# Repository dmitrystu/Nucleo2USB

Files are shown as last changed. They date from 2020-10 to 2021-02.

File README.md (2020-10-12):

## NUCLEO2USB SHIELD

NUCLEO2USB SHUELD

+ Compatible with NUCLEO-64 boards
+ Can be configured as 2xOTGFS, 1xOTGFS, 2xDEVFS, 1xDEVFS, 1xDEVFS+1xOTGFS
+ Can provide power to the baseboard from USB1 USB2 and STLINK(U5V) via E5V pin
+ USB FS/LS override jumper (for the NUCLEO-F303RE / NUCLEO-F103RB)
+ 2x micro USB TYPE B connectors
+ ESCDA5V3SC6 USB ESD protection
+ LM3526L USB-OTG power switch with over-current protection

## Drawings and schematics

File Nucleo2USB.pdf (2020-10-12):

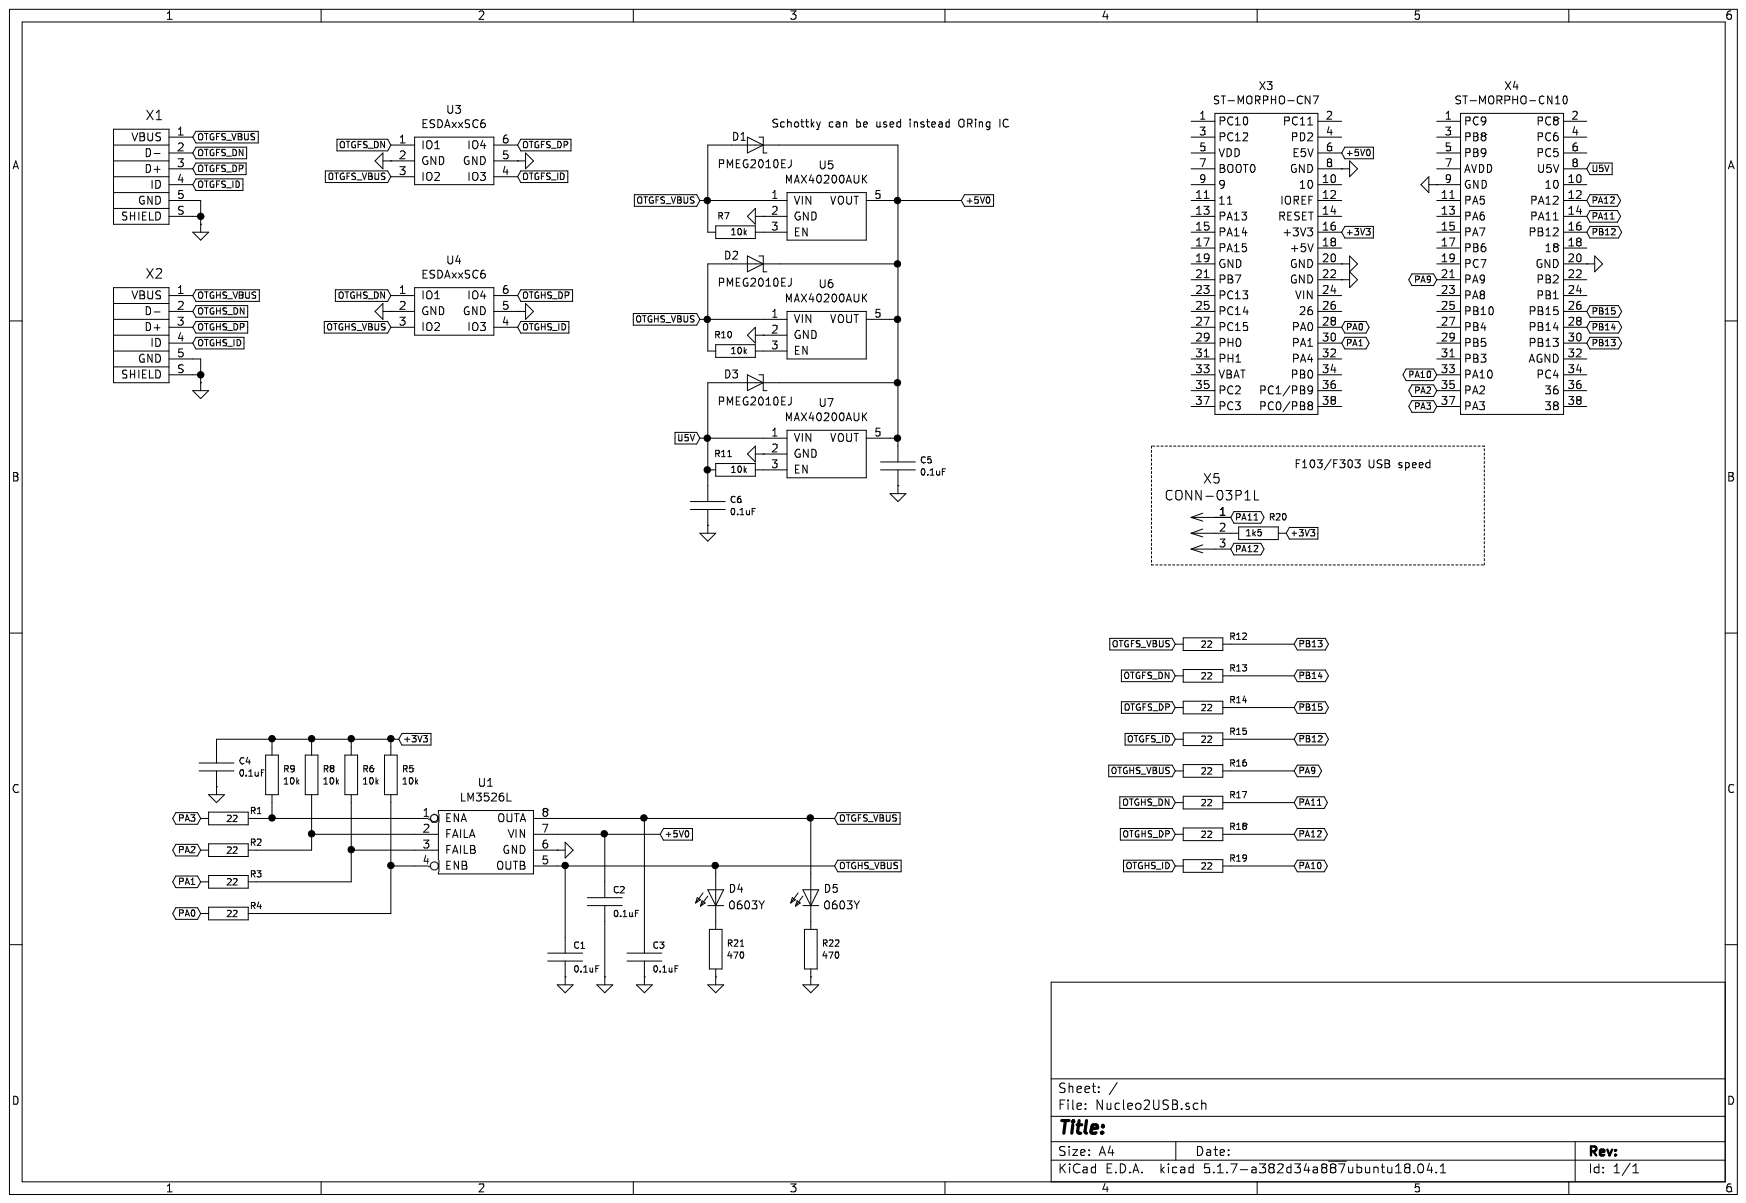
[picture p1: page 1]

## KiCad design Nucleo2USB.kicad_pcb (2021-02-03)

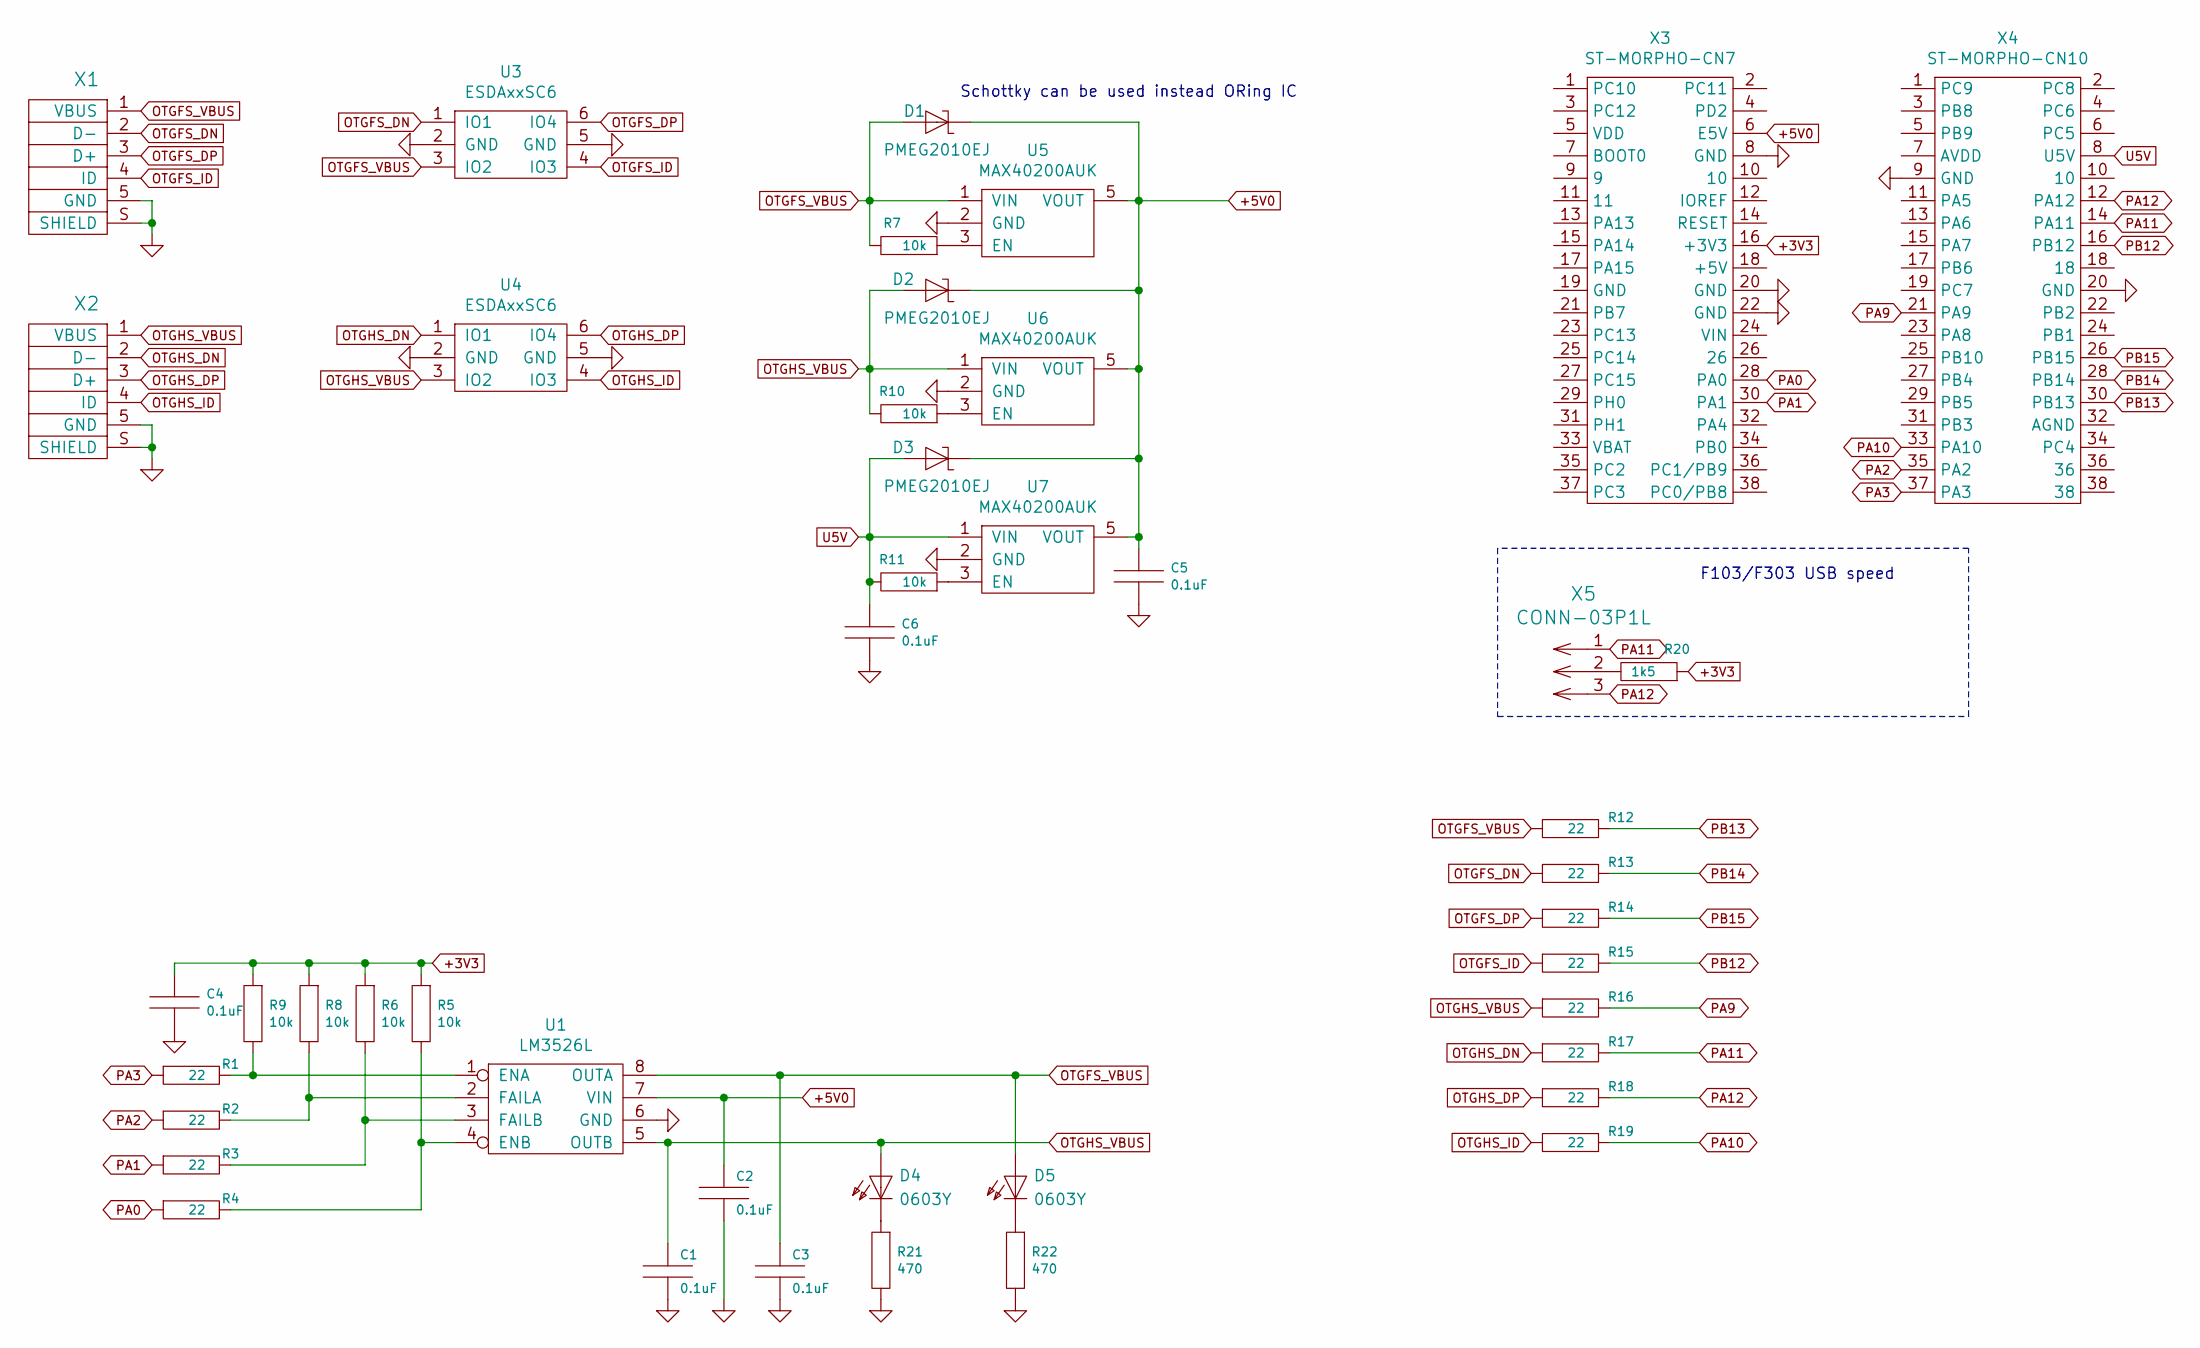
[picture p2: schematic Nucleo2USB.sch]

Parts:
C1, C2, C3, C4, C5, C6: 0.1uF; SMD-0603C
D1, D2, D3: PMEG2010EJ; SOD-123F
D4, D5: 0603Y; LED-0603
R1, R2, R3, R4, R12, R13, R14, R15, R16, R17, R18, R19: 22; SMD-0603R
R5, R6, R7, R8, R9, R10, R11: 10k; SMD-0603R
R20: 1k5; SMD-0603R
R21, R22: 470; SMD-0603R
U1: LM3526L; SO65P030X044-8
U3, U4: ESDAxxSC6; SOT-23-6
U5, U6, U7: MAX40200AUK; SOT-23-5
X1, X2: USB-OTG; AMP10118194-0001LF
X3: ST-MORPHO-CN7; DS1023-04-2X19A11
X4: ST-MORPHO-CN10; DS1023-04-2X19A11
X5: CONN-03P1L; DS1021-1X03S61

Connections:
+3V3: C4.1 (C1), R5.1 (R1), R6.1 (R1), R8.1 (R1), R9.1 (R1), R20.1 (R1), X3.16 (+3V3)
+5V0: C2.1 (C1), C5.1 (C1), D1.1 (K), D2.1 (K), D3.1 (K), U1.7 (VIN), U5.5 (VOUT), U6.5 (VOUT), U7.5 (VOUT), X3.6 (E5V)
AGND: C1.2 (C2), C2.2 (C2), C3.2 (C2), C4.2 (C2), C5.2 (C2), C6.2 (C2), R21.2 (R2), R22.2 (R2), U1.6 (GND), U3.2 (GND), U3.5 (GND), U4.2 (GND), U4.5 (GND), U5.2 (GND), U6.2 (GND), U7.2 (GND), X1.5 (GND), X1.S (SHIELD), X2.5 (GND), X2.S (SHIELD), X3.8 (GND), X3.20 (GND), X3.22 (GND), X4.9 (GND), X4.20 (GND)
unnamed: D4.K, R21.1 (R1)
unnamed: D5.K, R22.1 (R1)
unnamed: R1.2 (R2), R9.2 (R2), U1.1 (ENA)
unnamed: R2.2 (R2), R8.2 (R2), U1.2 (FAILA)
unnamed: R3.2 (R2), R6.2 (R2), U1.3 (FAILB)
unnamed: R4.2 (R2), R5.2 (R2), U1.4 (ENB)
unnamed: R7.1 (R1), U5.3 (EN)
unnamed: R10.1 (R1), U6.3 (EN)
unnamed: R11.1 (R1), U7.3 (EN)
unnamed: R20.2 (R2), X5.2
OTGFS_DN: R13.1 (R1), U3.1 (IO1), X1.2 (D-)
OTGFS_DP: R14.1 (R1), U3.6 (IO4), X1.3 (D+)
OTGFS_ID: R15.1 (R1), U3.4 (IO3), X1.4 (ID)
OTGFS_VBUS: C3.1 (C1), D1.2 (A), D5.A, R7.2 (R2), R12.1 (R1), U1.8 (OUTA), U3.3 (IO2), U5.1 (VIN), X1.1 (VBUS)
OTGHS_DN: R17.1 (R1), U4.1 (IO1), X2.2 (D-)
OTGHS_DP: R18.1 (R1), U4.6 (IO4), X2.3 (D+)
OTGHS_ID: R19.1 (R1), U4.4 (IO3), X2.4 (ID)
OTGHS_VBUS: C1.1 (C1), D2.2 (A), D4.A, R10.2 (R2), R16.1 (R1), U1.5 (OUTB), U4.3 (IO2), U6.1 (VIN), X2.1 (VBUS)
PA0: R4.1 (R1), X3.28 (PA0)
PA1: R3.1 (R1), X3.30 (PA1)
PA2: R2.1 (R1), X4.35 (PA2)
PA3: R1.1 (R1), X4.37 (PA3)
PA9: R16.2 (R2), X4.21 (PA9)
PA10: R19.2 (R2), X4.33 (PA10)
PA11: R17.2 (R2), X4.14 (PA11), X5.1
PA12: R18.2 (R2), X4.12 (PA12), X5.3
PB12: R15.2 (R2), X4.16 (PB12)
PB13: R12.2 (R2), X4.30 (PB13)
PB14: R13.2 (R2), X4.28 (PB14)
PB15: R14.2 (R2), X4.26 (PB15)
U5V: C6.1 (C1), D3.2 (A), R11.2 (R2), U7.1 (VIN), X4.8 (U5V)

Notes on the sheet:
F103/F303 USB speed
Schottky can be used instead ORing IC

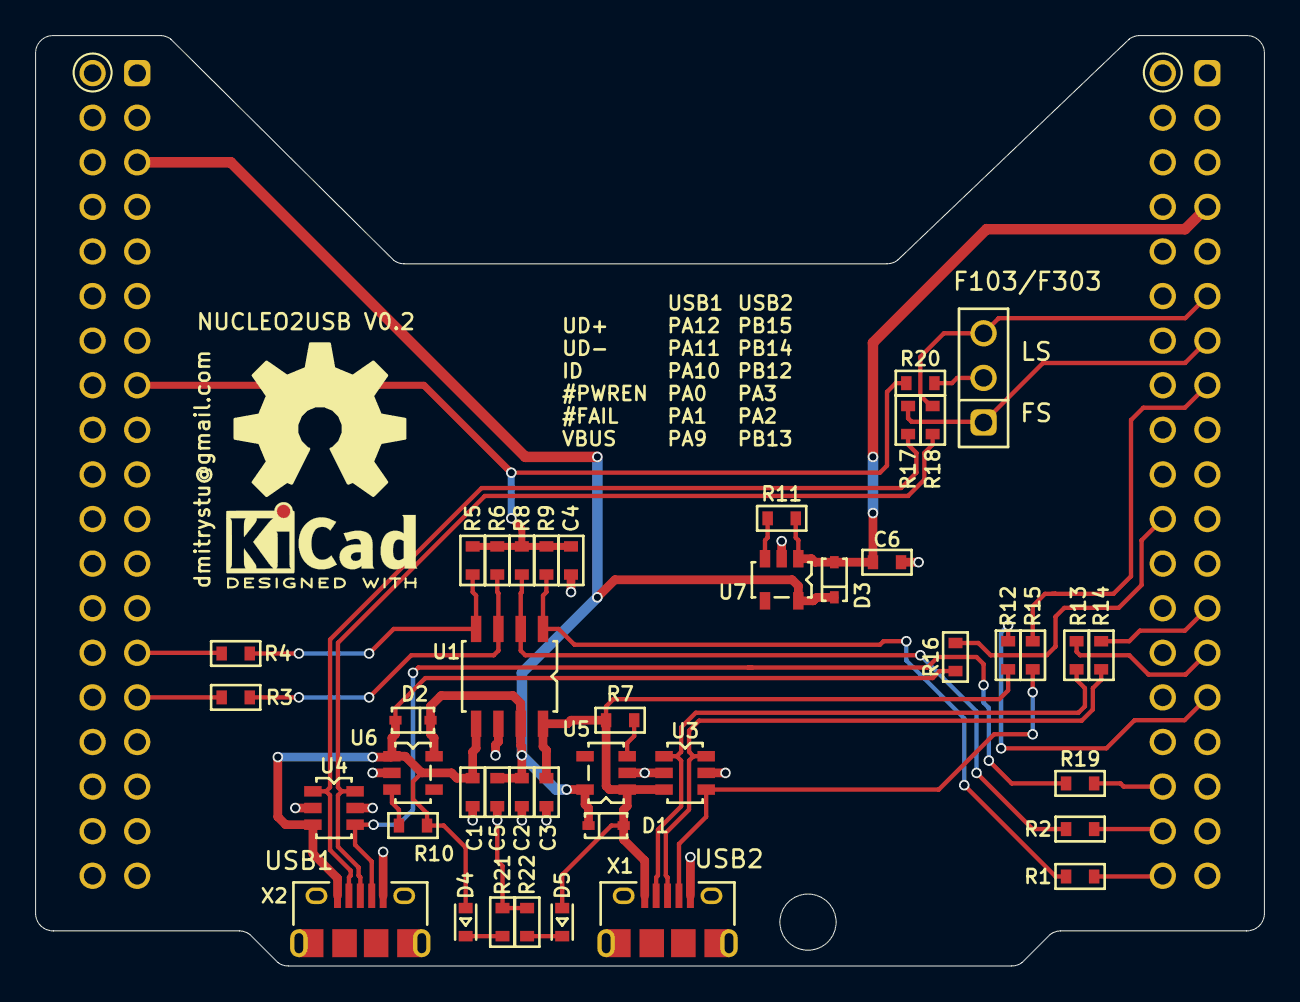
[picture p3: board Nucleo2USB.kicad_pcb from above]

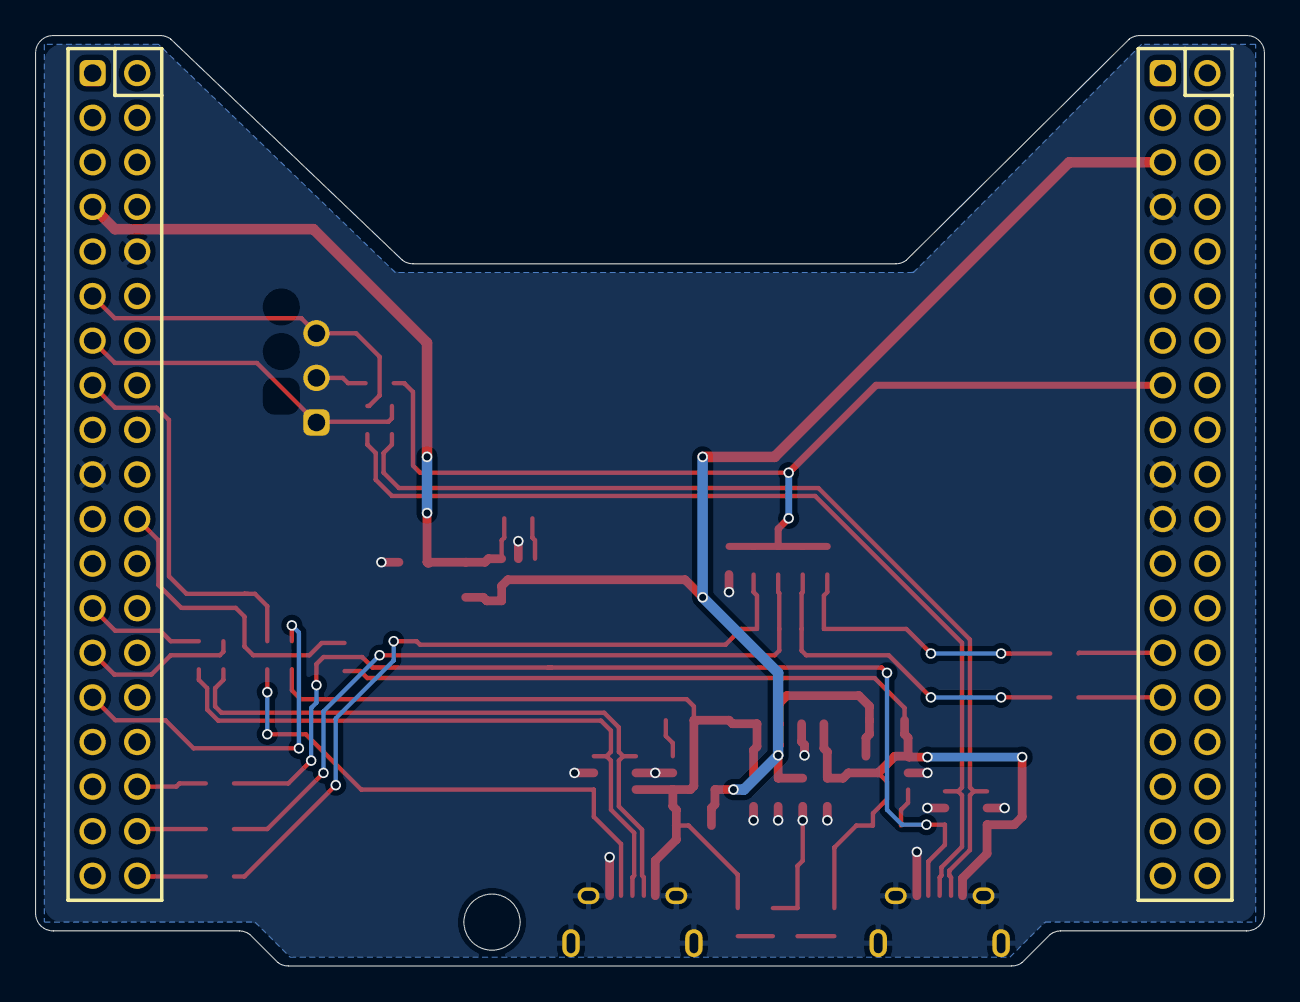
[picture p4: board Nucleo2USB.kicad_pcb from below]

Board: 2 copper layers, 70.0 x 53.0 mm, 45 parts (2 on the bottom side), 34 nets.

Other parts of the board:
OSHW_FS_10MM: VAL**; OSHW_FS_10MM

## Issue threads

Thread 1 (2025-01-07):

Brilliant! Is anyone selling hardware?

GrantMTG, 2025-01-07:
Thank you for doing this. It's such a mistake on ST's part not to have such a "shield"! Aside from having our own PCBs made, are you aware of anyone selling prebuilt boards?

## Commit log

2020-10-12 add PDF schematic
2021-02-03 update pcb, add cache library
    [Nucleo2USB.kicad_pcb]
